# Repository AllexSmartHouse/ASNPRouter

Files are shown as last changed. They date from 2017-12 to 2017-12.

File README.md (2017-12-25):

# ASNPRouter
Allex Serial Network Protocol router device based on stm32 board(blue pill) and arduino libs(STM32GENERIC)

# Hardware  
STM32 board - blue pill(or another with simillar pinout)  
Blue pill  

DC-DC converter(default PCB based on LM2596)
DC-DC converter  

PCB designed to use with cheap plastic case:  
cheap plastic case

# Software  
Arduino Libs:  
https://github.com/AllexSmartHouse/STM32GENERIC  

Use ST-Link  
Settings:  
Board: Blue pill  
USB: Disabled, No usb  
Serial communication: SerialUART1  
JTAG/SWD debugging: SWD
Upload method: ST-Link

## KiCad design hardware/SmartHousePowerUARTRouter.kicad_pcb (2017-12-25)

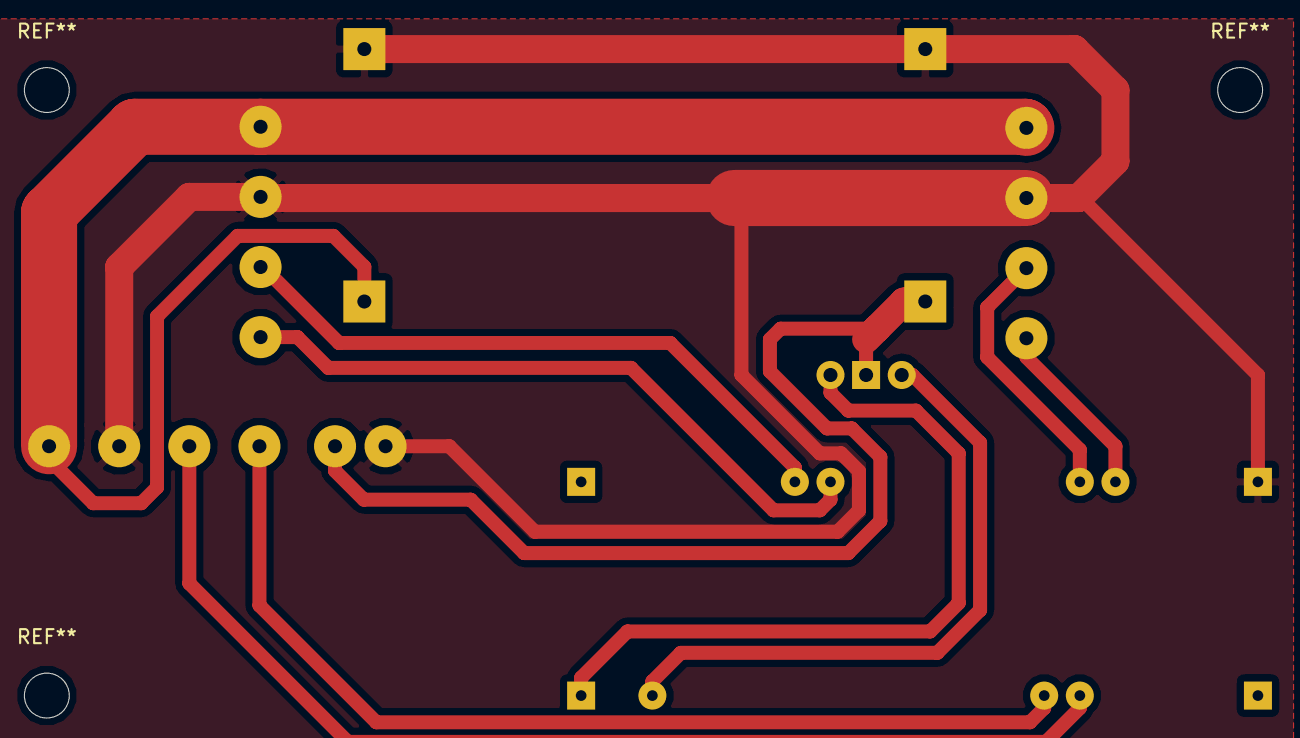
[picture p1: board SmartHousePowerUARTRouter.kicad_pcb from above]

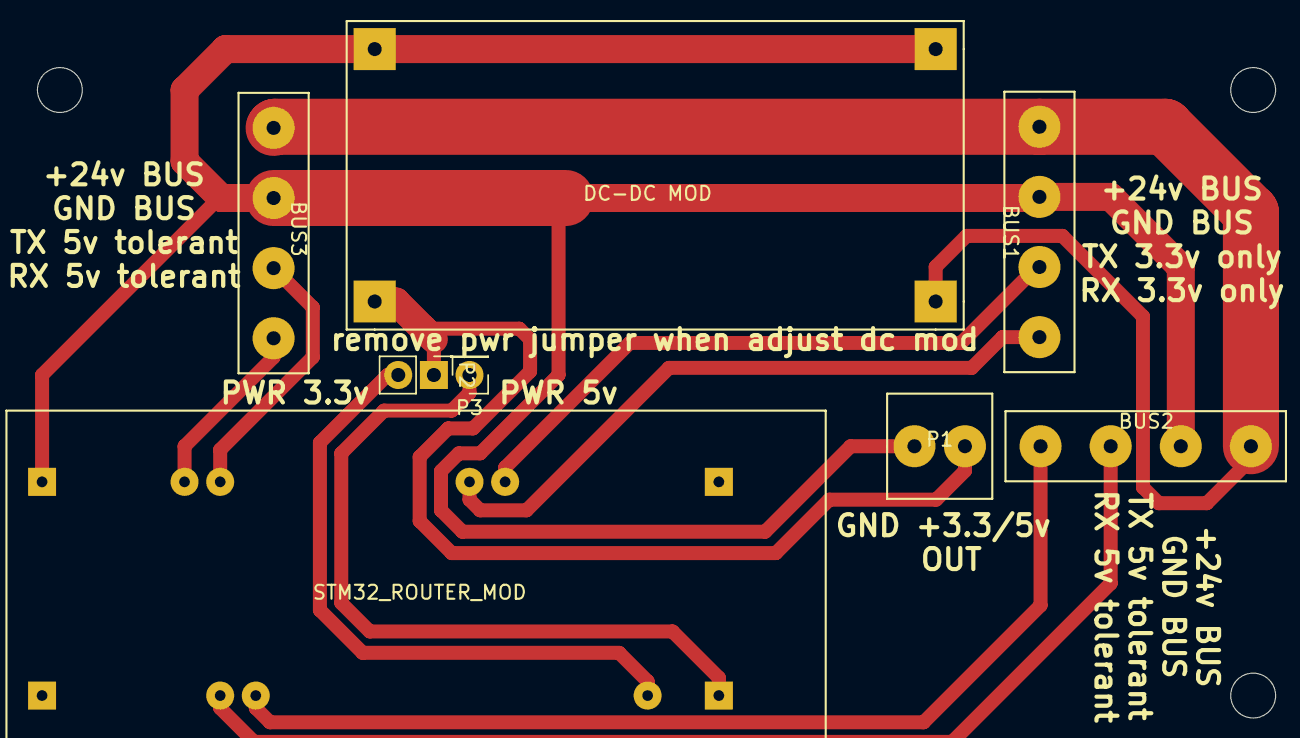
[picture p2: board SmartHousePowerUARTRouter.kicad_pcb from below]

Board: 2 copper layers, 8 parts (8 on the bottom side), 11 nets.

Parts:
BUS1, BUS2, BUS3: CONN_01X04; CONN_4_5mm
DC-DC MOD: LM2596_MOD
P1: CONN_01X02; CONN_2_3.5mm
P2: CONN_01X02; Pin_Header_Straight_1x02_Pitch2.54mm
P3: CONN_01X01; Pin_Header_Straight_1x01_Pitch2.54mm
STM32_ROUTER_MOD: STM32DISCOVERY; STM32_DISCOVERY

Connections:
unnamed: BUS1.1, STM32_ROUTER_MOD.28
unnamed: BUS1.2, STM32_ROUTER_MOD.27
unnamed: BUS1.3, BUS2.2, BUS3.2, DC-DC MOD.1, DC-DC MOD.4, P1.2, STM32_ROUTER_MOD.40
unnamed: BUS1.4, BUS2.1, BUS3.1, DC-DC MOD.2
unnamed: BUS2.3, STM32_ROUTER_MOD.15
unnamed: BUS2.4, STM32_ROUTER_MOD.14
unnamed: BUS3.3, STM32_ROUTER_MOD.35
unnamed: BUS3.4, STM32_ROUTER_MOD.36
unnamed: DC-DC MOD.3, P1.1, P2.1
unnamed: P2.2, STM32_ROUTER_MOD.3
unnamed: P3.1, STM32_ROUTER_MOD.1

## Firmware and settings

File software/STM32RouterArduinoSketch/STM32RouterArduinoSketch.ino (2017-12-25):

#include "PortHandler.h"
#include "SysMessageHandler.h"
#include "stm32f1xx_hal_iwdg.h"

const long long OVERFLOW_TIME = 2000;
const long long OVERFLOW_BLINK_TIME = 100;
const long long ERROR_TIME = 5000;
const long long ERROR_BLINK_TIME = 500;

long long overflowTime = 0;
long long errorTime = 0;

IWDG_HandleTypeDef hiwdg;
void startWatchDog(){
  hiwdg.Instance = IWDG;
  hiwdg.Init.Prescaler = IWDG_PRESCALER_32;
  hiwdg.Init.Reload    = 1000;
  
  HAL_IWDG_Init(&hiwdg);
}

void resetWatchDog(){
  HAL_IWDG_Refresh(&hiwdg);
}

const long DEFAULT_BAUD_RATE = 19200;

const int PORTS_COUNT = 3;
cPortHandler* ports[PORTS_COUNT];

cSysMessageHandler* sysMsgHandler;


void offLed(){
  digitalWrite(LED_BUILTIN,HIGH);
}

void onLed(){
  digitalWrite(LED_BUILTIN,LOW);
}

long long lastUpdate = 0;

void setup() {  
  pinMode(LED_BUILTIN, OUTPUT);
  digitalWrite(LED_BUILTIN,LOW);

  Serial1.begin(DEFAULT_BAUD_RATE);
  Serial2.begin(DEFAULT_BAUD_RATE);
  Serial3.begin(DEFAULT_BAUD_RATE);  

  ports[0] = new cPortHandler(&Serial1);
  ports[1] = new cPortHandler(&Serial2);
  ports[2] = new cPortHandler(&Serial3);

  sysMsgHandler = new cSysMessageHandler(ports, PORTS_COUNT);

  delay(400);
  //request all devices with listener addresses
  for (int i = 0; i<PORTS_COUNT; ++i)
    ports[i]->queuePackage(PING_BROADCAST);

  startWatchDog();
  

  lastUpdate = millis();
}

bool processPort(int portIndex, long dt){
  if (ports[portIndex]->processData(dt)){    
    uint8_t* receivedPackage = ports[portIndex]->getReceivedPackage();
    sSysMessageInfo state =  sysMsgHandler->getMessageInfo(receivedPackage);

    if (state.needSysHandling){    
      sysMsgHandler->processSysMessage(receivedPackage, portIndex);
    }
    
    if (state.needDefaultHandling){
      for (int i = 0; i<PORTS_COUNT; ++i)
        if (i!=portIndex){
          ports[i]->queuePackage(receivedPackage);
        }
    }
    ports[portIndex]->clearReceivedPackage();
    return true;
  }
  return false;
}

void loop() {
  resetWatchDog();
  
  long long currentTime = millis();
  long dt = currentTime - lastUpdate;
  if (currentTime<lastUpdate)
    dt = currentTime;
  lastUpdate = currentTime;

  bool haveData = false;

  if (processPort(0, dt))
    haveData = true;
  if (processPort(1, dt))
    haveData = true;
  if (processPort(2, dt))
    haveData = true;

  for (int i = 0; i<PORTS_COUNT; ++i){
    if (ports[i]->isOverflow()){
      overflowTime = OVERFLOW_TIME;
    }
    if (ports[i]->isDataError() && errorTime<=0){
      errorTime = ERROR_TIME;
    }
  }
  if (sysMsgHandler->isDataError() && errorTime<=0){
    errorTime = ERROR_TIME;
  }
  sysMsgHandler->update(dt);

  bool canSleep = true;
  for (int i = 0; i<PORTS_COUNT; ++i){
    if (ports[i]->startSending())
      canSleep = false;
  }
  

  if (errorTime>0){    
    errorTime-=dt;
    if (errorTime>0){
      if (currentTime / ERROR_BLINK_TIME % 2 == 0){
        onLed();
      }
      else{
        offLed();  
      }
    }
    else{
      offLed();
    }    
  }
  else{
    if (overflowTime>0){
      overflowTime-=dt;
      if (overflowTime>0){
        if (currentTime / OVERFLOW_BLINK_TIME % 2 == 0){
          onLed();
        }
        else{
          offLed();  
        }
      }
      else{
        offLed();
      }
    }
    else{
      //NO ERROR
      //SHOW DATA ACTIVITY
      if (haveData){
        onLed();
      }
      else{
          offLed();
        if (canSleep)
          delay(10);
      }
    }
  }
}
